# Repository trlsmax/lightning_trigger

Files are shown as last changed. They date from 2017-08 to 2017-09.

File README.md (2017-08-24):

# lightning_trigger
trigger the camera to capture lightning

sensor and filter circuit come from this [BLOG][1]

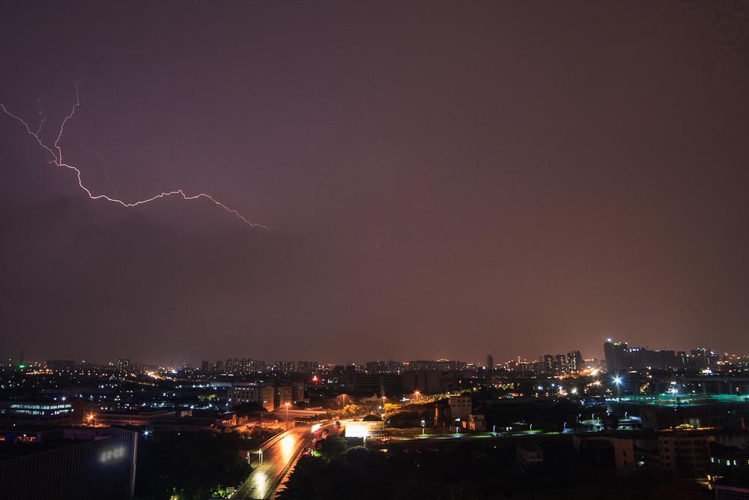
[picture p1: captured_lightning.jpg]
Captured Lightning


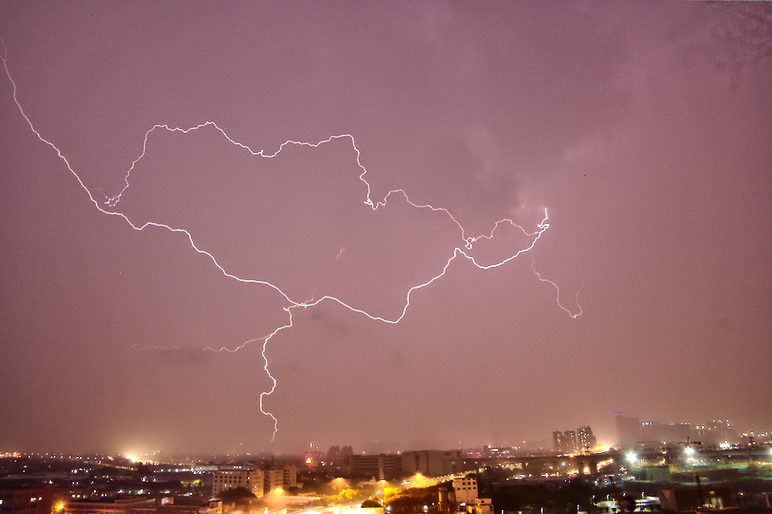
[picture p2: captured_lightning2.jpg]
Captured Lightning 2


[1]:http://diy.viktak.com/2011/03/zeus-lightning-trigger-for-cameras.html

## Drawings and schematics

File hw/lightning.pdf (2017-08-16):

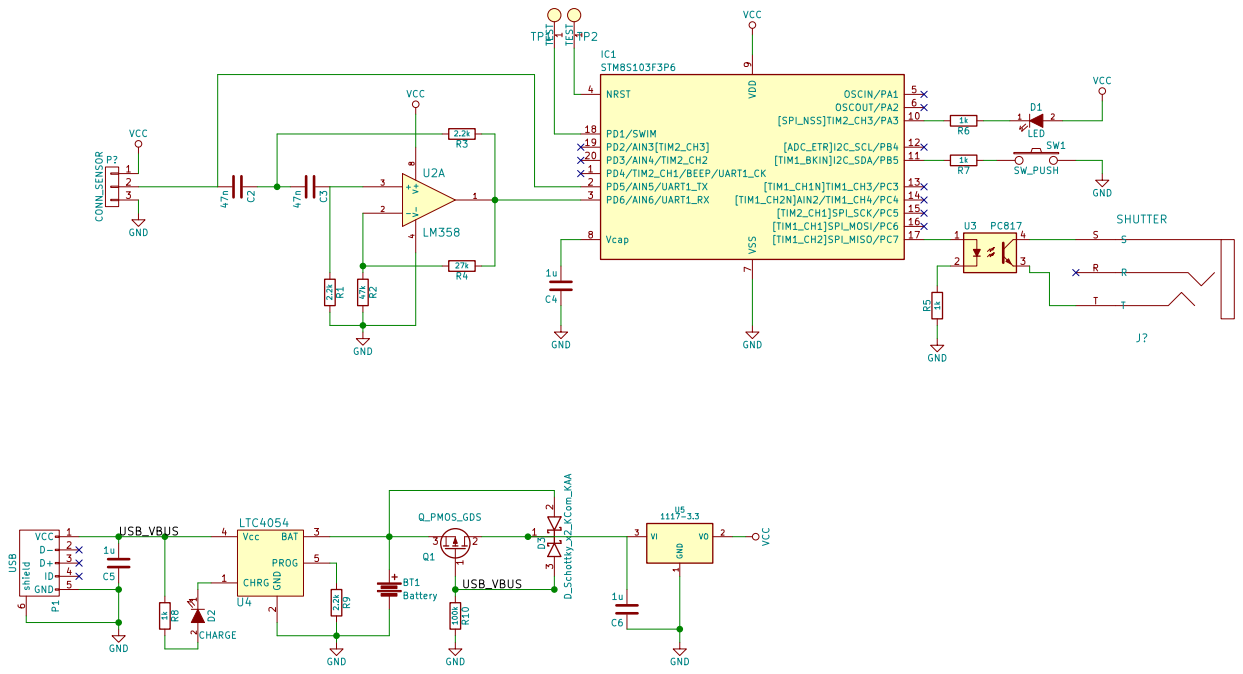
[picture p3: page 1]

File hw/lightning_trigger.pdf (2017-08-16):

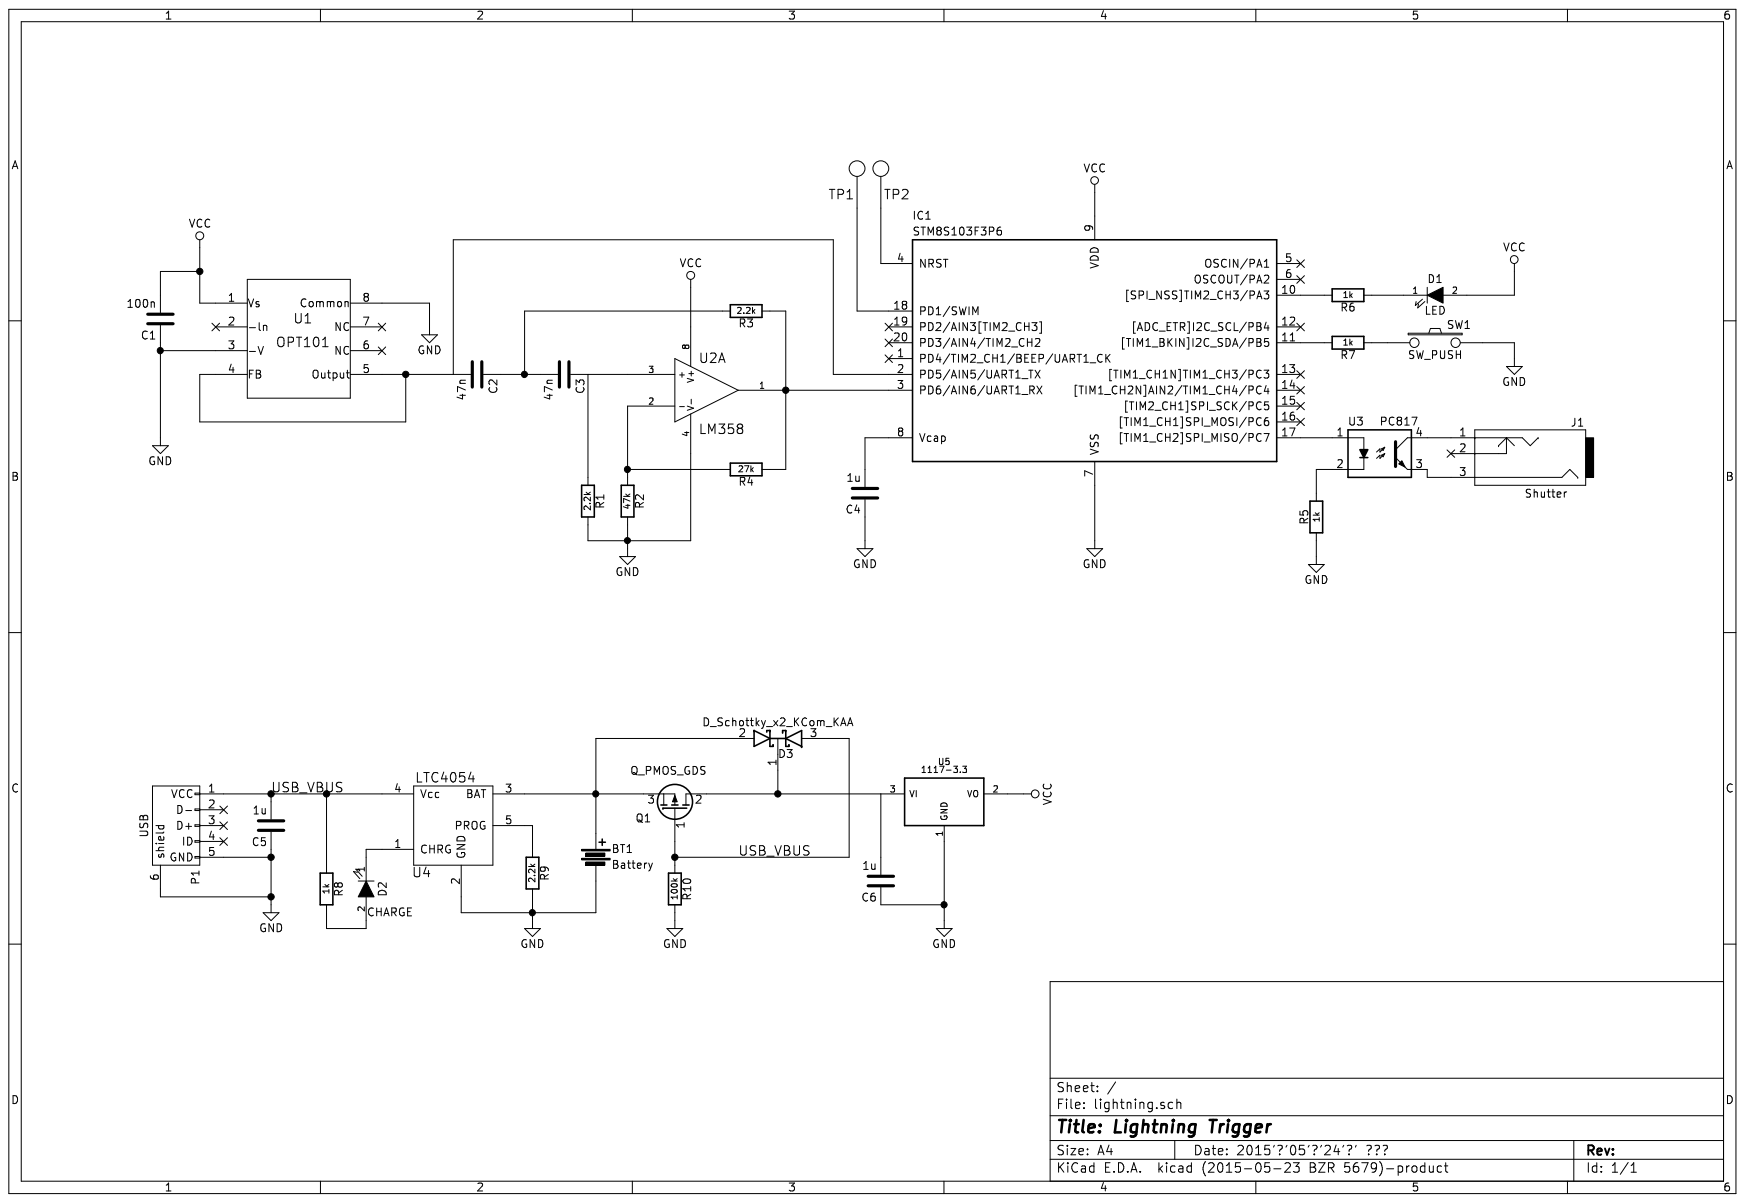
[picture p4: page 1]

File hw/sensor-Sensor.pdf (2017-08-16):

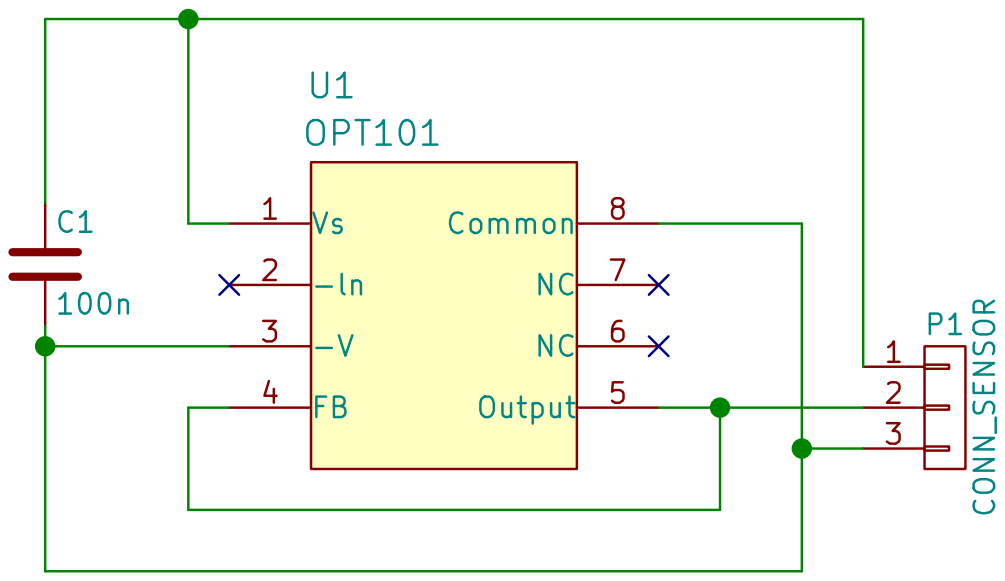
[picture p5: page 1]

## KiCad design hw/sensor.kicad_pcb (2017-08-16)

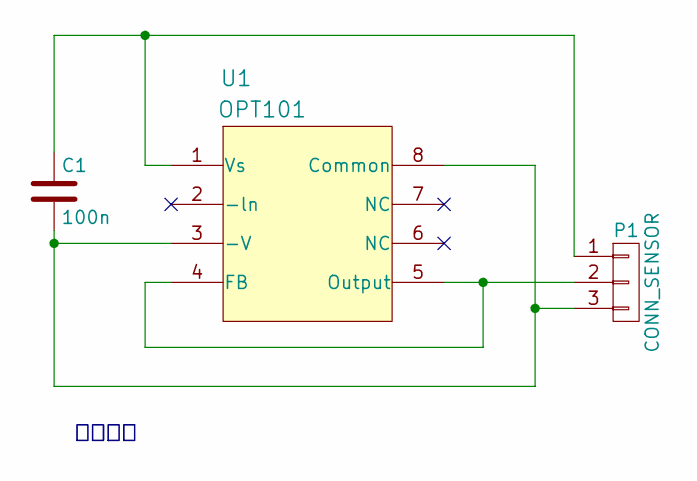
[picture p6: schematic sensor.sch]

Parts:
C1: 100n; C_0603
P1: CONN_SENSOR; Pin_Header_Straight_1x03
U1: OPT101; DIP-8__300_ELL

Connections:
unnamed: C1.1, P1.1, U1.1 (Vs)
unnamed: C1.2, P1.3, U1.3 (-V), U1.8 (Common)
unnamed: P1.2, U1.4 (FB), U1.5 (Output)

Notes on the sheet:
转危为安

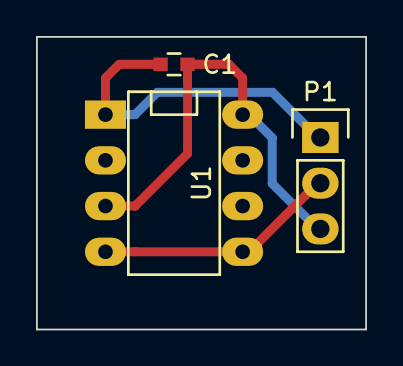
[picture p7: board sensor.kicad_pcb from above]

Board: 2 copper layers, 18.3 x 16.3 mm, 3 parts (0 on the bottom side), 3 nets.

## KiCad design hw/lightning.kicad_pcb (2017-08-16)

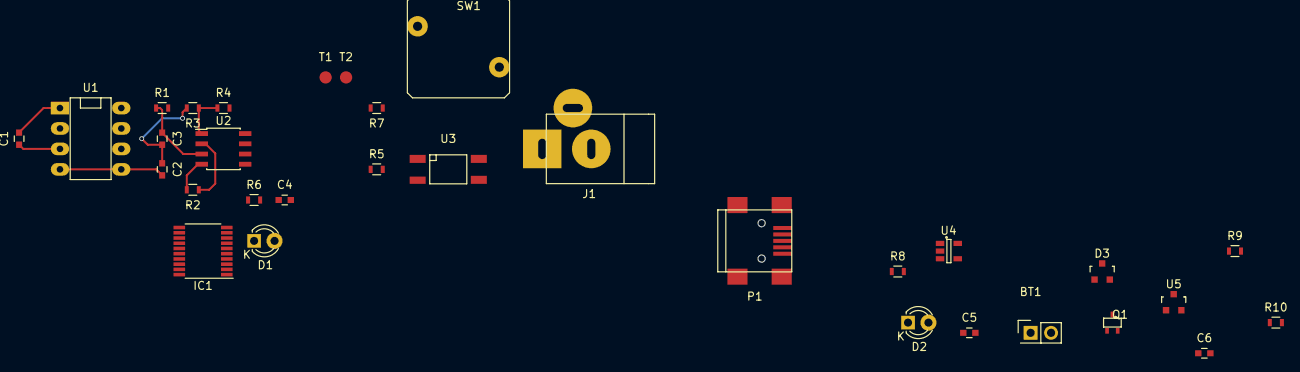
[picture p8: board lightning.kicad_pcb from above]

Board: 2 copper layers, 32 parts (0 on the bottom side), 25 nets.

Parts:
BT1: Battery; Pin_Header_Straight_2x01
C1: 100n; C_0603
C2, C3: 47n; C_0603
C4, C5, C6: 1u; C_0603
D1: LED; LED-3MM
D2: CHARGE; LED-3MM
D3: D_Schottky_x2_KCom_KAA; SOT-23
IC1: STM8S103F3P6; TSSOP-20_4.4x6.5mm_Pitch0.65mm
J1: Shutter; JACK_ALIM
P1: USB_OTG; USB_Mini-B
Q1: Q_PMOS_GDS; sc70
R1, R3, R9: 2.2k; R_0603
R2: 47k; R_0603
R4: 27k; R_0603
R5, R6, R7, R8: 1k; R_0603
R10: 100k; R_0603
SW1: SW_PUSH
T1: SWIM; Measurement_Point_Round-SMD-Pad_Small
T2: NRST; Measurement_Point_Round-SMD-Pad_Small
U1: OPT101; DIP-8__300_ELL
U2: LM358; SOIC-8_3.9x4.9mm_Pitch1.27mm
U3: PC817; Optocoupler_SMD_HandSoldering_KPC357_LTV35x_PC357_SingleCha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
U4: LTC4054; SOT-23-5
U5: NCP1117ST33T3G; SOT-23

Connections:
/USB_VBUS: C5.2, D3.3, P1.1, Q1.1, R8.1, R10.1, U4.4
GND: BT1.2, C4.1, C5.1, C6.1, IC1.7, P1.5, P1.6, R1.2, R2.2, R5.1, R9.2, R10.2, SW1.2, U1.8, U2.4, U4.2, U5.1
unnamed: BT1.1, D3.2, Q1.3, U4.3
unnamed: C1.1, U1.3
unnamed: C2.1, C3.2, R3.2
unnamed: C2.2, IC1.2, U1.4, U1.5
unnamed: C3.1, R1.1, U2.3
unnamed: C4.2, IC1.8
unnamed: C6.2, D3.1, Q1.2, U5.3
unnamed: D1.1, R6.1
unnamed: D2.1, U4.1
unnamed: D2.2, R8.2
unnamed: IC1.3, R3.1, R4.1, U2.1
unnamed: IC1.4, T2.1
unnamed: IC1.10, R6.2
unnamed: IC1.11, R7.2
unnamed: IC1.17, U3.1
unnamed: IC1.18, T1.1
unnamed: J1.1, U3.4
unnamed: J1.3, U3.3
unnamed: R2.1, R4.2, U2.2
unnamed: R5.2, U3.2
unnamed: R7.1, SW1.1
unnamed: R9.1, U4.5
VCC: C1.2, D1.2, IC1.9, U1.1, U2.8, U5.2

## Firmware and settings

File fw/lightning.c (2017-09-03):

#include <stdio.h>
#include <string.h>
#include "stm8s.h"

#define FALSE 0
#define TRUE 1

//#define DEBUG_ENABLE

/* mirror lockup will stop when there is no 
 * shutter trigger in 25 seconds on Canon 350D
 * */
#define MIRROR_LOCKUP_AUTO_RESTART

#define BG_INTERVAL 5000           // get background light level every BG_INTERVAL sec
#define TRIGGER_OFFSET 5

#ifdef MIRROR_LOCKUP_AUTO_RESTART
#define MIRROR_TIMEOUT 30500
#endif

#ifdef STM8S105                 // config for STM8S-DISCOVERY board
#define CH_BACKGROUND 4
#define CH_HIGHPASS 9
#define SHUTTER_PORT GPIOB
#define SHUTTER_PIN 0x80        //PB7
#define UART UART2
#define UART_SR_TXE UART2_SR_TXE
#define UART_CR2_TEN UART2_CR2_TEN
#define TXD_PORT GPIOD
#define TXD_PIN 0x20            //PD5
#define ML_PORT GPIOD
#define ML_PIN 0x80
#elif defined(STM8S103)         // config for my STM8S103 board
#define CH_BACKGROUND 5
#define CH_HIGHPASS 6
#define SHUTTER_PORT GPIOC
#define SHUTTER_PIN 0x80        //PB7
#define UART UART1
#define UART_SR_TXE UART1_SR_TXE
#define UART_CR2_TEN UART1_CR2_TEN
#define TXD_PORT GPIOD
#define TXD_PIN 0x20            //PD5
#define ML_PORT GPIOB
#define ML_PIN 0x20
#endif

volatile bool lightning_trg = FALSE;
bool mirror_lockup_enable = FALSE;
uint16_t *buf_ptr;
volatile uint16_t time_cnt = 0;

#ifdef MIRROR_LOCKUP_AUTO_RESTART
volatile bool do_mirror_lockup = FALSE;
volatile uint16_t mirror_cnt = 0;
#endif

void delay_ms(uint16_t t)
{
    time_cnt = t;
    while(time_cnt > 0);
}

#ifdef DEBUG_ENABLE
bool bg_flag = FALSE;
uint16_t tmp;
/* ========================================================================== */
/**
 * @brief   putchar send a char to UART2 for printf func
 *
 * @param   c char to send
 *
 * @return  
 */
/* ========================================================================== */
int putchar(int c)
{
    while(!(UART->SR & UART_SR_TXE));
    UART->DR = (uint8_t)c;
    return 0;
}
#endif

/* ========================================================================== */
/**
 * @brief   main main func
 */
/* ========================================================================== */
void main(void) 
{
    uint32_t i = 0;

    CLK->CKDIVR = 0x00;                             // Set the frequency to 16 MHz
    CLK->PCKENR1 = 0x88;                            // Enable TIM1 & UART2 peripherals
    CLK->PCKENR2 = 0x08;                            // Enable ADC1 peripherals

    /* setting up shutter io */
    SHUTTER_PORT->DDR |= SHUTTER_PIN;
    SHUTTER_PORT->CR1 |= SHUTTER_PIN;
    SHUTTER_PORT->CR2 |= SHUTTER_PIN;
    SHUTTER_PORT->ODR = 0;

    /* mirror lockup pin setup */
    ML_PORT->CR1 |= ML_PIN;                         //input , pull up, no interrupt

#ifdef DEBUG_ENABLE
    TXD_PORT->DDR |= TXD_PIN;                       // Put TX line on
    TXD_PORT->CR1 |= TXD_PIN;
    TXD_PORT->CR2 |= TXD_PIN;

    UART->CR2 = UART_CR2_TEN;                       // Allow TX & RX
    UART->BRR2 = 0x0B; UART->BRR1 = 0x08;           // 115200 baud
#endif

    buf_ptr = (uint16_t *)&ADC1->DB0RH;             //set a pointer to ADC data buffer
    /* set adc1 to continue buffered mode to get background light level 
     * and set it to high threathold for lightning trigger*/
    ADC1->CR1 &= ~ADC1_CR1_ADON;                    //power off
    ADC1->CR2 |= ADC1_CR2_ALIGN;                    //right alignment
    ADC1->CR1 |= ADC1_CR1_CONT;                     //Continuous
    ADC1->CR3 |= ADC1_CR3_DBUF;                     //buffer
    ADC1->CSR |= (ADC1_CSR_CH & CH_BACKGROUND);     // set input channel
    ADC1->CSR |= ADC1_CSR_EOCIE;                    //set end of conversion interrupt
    ADC1->TDRL = 0xFF;                              //disable sthmit trigger
    ADC1->TDRH = 0xFF;
    ADC1->HTRL = ADC1_HTRL_RESET_VALUE;
    ADC1->HTRH = ADC1_HTRH_RESET_VALUE;
    ADC1->LTRL = ADC1_LTRL_RESET_VALUE;
    ADC1->LTRH = ADC1_LTRH_RESET_VALUE;
    ADC1->CR1 |= ADC1_CR1_ADON;                     //power on
    ADC1->CR1 |= ADC1_CR1_ADON;                     //start conversion

    /*
     * set up 1ms timer interrupt
     * to get background light level every BG_INTERVAL ms
     */
    TIM1->ARRH = (uint8_t)(500 >> 8);               //auto reload value
    TIM1->ARRL = (uint8_t)500;
    TIM1->PSCRH = 0;                                //prescaler
    TIM1->PSCRL = (uint8_t)31;
    TIM1->IER |= TIM1_IER_UIE;                      //enable update interrupt
    TIM1->RCR = 0;                                  //disable repeat counter
    TIM1->CR1 = TIM1_CR1_RESET_VALUE;
    TIM1->CR1 |= TIM1_CR1_ARPE;                     //auto reload
    TIM1->CR1 |= TIM1_CR1_CEN;

    enableInterrupts();
    delay_ms(1000);

    // read mirror lockup switch
    mirror_lockup_enable = ((ML_PORT->IDR & ML_PIN) == 0);

    if (mirror_lockup_enable) {
        //mirror lockup enable
        SHUTTER_PORT->ODR |= SHUTTER_PIN;
        delay_ms(100);
        SHUTTER_PORT->ODR &= ~SHUTTER_PIN;
    }

    do {
        /* trigger camera */
        if (lightning_trg) {
            SHUTTER_PORT->ODR |= SHUTTER_PIN;
#ifdef DEBUG_ENABLE
            //print trigger light level
            printf("lightning = %d !\n\r", tmp);
#endif
            delay_ms(100);
            SHUTTER_PORT->ODR &= ~SHUTTER_PIN;

            if (mirror_lockup_enable) {
                // here, shutter duration should less than 2000 ms
                delay_ms(2000);
                //mirror lockup enable
                SHUTTER_PORT->ODR |= SHUTTER_PIN;
                delay_ms(100);
                SHUTTER_PORT->ODR &= ~SHUTTER_PIN;
#ifdef MIRROR_LOCKUP_AUTO_RESTART
                //reset mirror timeout counter
                mirror_cnt = MIRROR_TIMEOUT;
#endif
            }

            lightning_trg = FALSE;
            ADC1->CR1 |= ADC1_CR1_ADON;                         //power on
            ADC1->CR1 |= ADC1_CR1_ADON;                         //start conversion
        }


#ifdef DEBUG_ENABLE
        //print background light level
        if (bg_flag) {
            bg_flag = FALSE;
            printf("background = %d\n\r", tmp);
        }
#endif

#ifdef MIRROR_LOCKUP_AUTO_RESTART
        if (mirror_lockup_enable && do_mirror_lockup) {
            do_mirror_lockup = FALSE;
            //mirror lockup enable
            SHUTTER_PORT->ODR |= SHUTTER_PIN;
            delay_ms(100);
            SHUTTER_PORT->ODR &= ~SHUTTER_PIN;
            //reset mirror timeout counter
            mirror_cnt = MIRROR_TIMEOUT;
        }
#endif
    } while(1);
}

/* ========================================================================== */
/**
 * @brief   tim1_update tim1 ISR , 1 sec timer, count BG_INTERVAL sec to
 *                      get background light level
 *
 * @param   none
 */
/* ========================================================================== */
void tim1_update(void) __interrupt(ISR_TIM1_OVF)
{
    static uint16_t sec = 0;

    if (time_cnt > 0)
        time_cnt--;

#ifdef MIRROR_LOCKUP_AUTO_RESTART
    if (mirror_cnt > 0) {
        if (--mirror_cnt == 0)
            do_mirror_lockup = TRUE;
    }
#endif

    if (sec++ > BG_INTERVAL) {
        sec = 0;
        /*************************************************
         * set adc1 to buffered continue mode
         * and get background light level
         * **********************************************/
        ADC1->CR1 &= ~ADC1_CR1_ADON;                    //power off
        ADC1->CR3 |= ADC1_CR3_DBUF;                     //buffer mode
        //ADC1->CSR &= ~ADC1_CSR_CH;
        //ADC1->CSR |= (ADC1_CSR_CH & CH_BACKGROUND);   //select background channel
        //ADC1->CSR |= ADC1_CSR_EOCIE;                  //enable end of conversion isr
        //ADC1->CSR &= ~ADC1_CSR_AWDIE;                 //disable AWD
        ADC1->CSR = 0x24;
        ADC1->CR1 |= ADC1_CR1_ADON;                     //power on
        ADC1->CR1 |= ADC1_CR1_ADON;                     //start conversion
    }

    TIM1->SR1 &= ~(TIM1_SR1_UIF);                       //clear update flag
}

/* ========================================================================== */
/**
 * @brief   adc ADC1 ISR, background light level calculate and setting
 *              lightning trigger level, when lightning detected, trigger
 *              the camera shutter
 *
 * @param   none
 */
/* ========================================================================== */
void adc(void) __interrupt(ISR_ADC1)
{
    uint8_t i;
    uint32_t sum;

    if (ADC1->CSR & ADC1_CSR_AWD) {                     //AWD interrupt
        ADC1->CSR &= ~ADC1_CSR_AWDIE;                   //disable AWD interrupt
        /*************************************************
         * detected lightning bolt
         * and trigger camera shutter
         * **********************************************/
        if (lightning_trg == FALSE) {
            SHUTTER_PORT->ODR |= SHUTTER_PIN;           //trigger camera shutter
            ADC1->CR1 &= ~ADC1_CR1_ADON;                    //power off
            lightning_trg = TRUE;
#ifdef DEBUG_ENABLE
            tmp = *(uint16_t*)&ADC1->DRH;               //store the trigger value for print
#endif
        }
        ADC1->CSR &= ~ADC1_CSR_AWD;                     //clear interrupt flag
        ADC1->CSR &= ~ADC1_CSR_EOC;                     //clear interrupt flag
        ADC1->CSR |= ADC1_CSR_AWDIE;                    //enable AWD interrupt
    } else if (ADC1->CSR & ADC1_CSR_EOC) {              //end of conversion
        ADC1->CR1 &= ~ADC1_CR1_ADON;                    //power off

        /***************************************************
         * everage 8 sample to be the background light level
         **************************************************/
        sum = 0;
        for(i = 0; i < 10; i++)
            if (sum < buf_ptr[i])
                sum = buf_ptr[i];
        sum += TRIGGER_OFFSET;

#ifdef DEBUG_ENABLE
        tmp = sum;                                      //store everage value for print
        bg_flag = TRUE;                                 //print flag
#endif
        /*************************************************
         * set adc1 to non-buffered continue mode
         * and trigger by light level greater that 
         * high threathold
         * **********************************************/
        ADC1->CR3 &= ~ADC1_CR3_DBUF;                        //buffer mode
        //ADC1->CSR &= ~ADC1_CSR_EOC;                       //clear interrupt flag
        //ADC1->CSR &= ~ADC1_CSR_CH;
        //ADC1->CSR |= (ADC1_CSR_CH & CH_HIGHPASS);         //select highpass channel
        //ADC1->CSR &= ~ADC1_CSR_EOCIE;                     //set end of conversion interrupt
        //ADC1->CSR |= ADC1_CSR_AWDIE;                      //enable AWD interrupt
        ADC1->CSR = 0x19;
        ADC1->HTRL = (sum & 3);                             //set AWD
        ADC1->HTRH = (sum >> 2);
        ADC1->CR1 |= ADC1_CR1_ADON;                         //power on
        ADC1->CR1 |= ADC1_CR1_ADON;                         //start conversion
    }
}

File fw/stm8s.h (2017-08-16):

/**
  ******************************************************************************
  * @file    stm8s.h
  * @author  MCD Application Team
  * @version V2.1.0
  * @date    18-November-2011
  * @brief   This file contains all HW registers definitions and memory mapping.
  ******************************************************************************
  * @attention
  *
  * THE PRESENT FIRMWARE WHICH IS FOR GUIDANCE ONLY AIMS AT PROVIDING CUSTOMERS
  * WITH CODING INFORMATION REGARDING THEIR PRODUCTS IN ORDER FOR THEM TO SAVE
  * TIME. AS A RESULT, STMICROELECTRONICS SHALL NOT BE HELD LIABLE FOR ANY
  * DIRECT, INDIRECT OR CONSEQUENTIAL DAMAGES WITH RESPECT TO ANY CLAIMS ARISING
  * FROM THE CONTENT OF SUCH FIRMWARE AND/OR THE USE MADE BY CUSTOMERS OF THE
  * CODING INFORMATION CONTAINED HEREIN IN CONNECTION WITH THEIR PRODUCTS.
  *
  * <h2><center>&copy; COPYRIGHT 2011 STMicroelectronics</center></h2>
  ******************************************************************************
  */

/* Define to prevent recursive inclusion -------------------------------------*/
#ifndef __STM8S_H
#define __STM8S_H

/** @addtogroup STM8S_StdPeriph_Driver
  * @{
  */

/* Uncomment the line below according to the target STM8S or STM8A device used in your
   application. */

 /* #define STM8S208 */      /*!< STM8S High density devices with CAN */
 /* #define STM8S207 */      /*!< STM8S High density devices without CAN */
 /* #define STM8S007 */      /*!< STM8S Value Line High density devices */
 /* #define STM8AF52Ax */    /*!< STM8A High density devices with CAN */
 /* #define STM8AF62Ax */    /*!< STM8A High density devices without CAN */
 /* #define STM8S105 */     /*!< STM8S Medium density devices */
 /* #define STM8S005 */      /*!< STM8S Value Line Medium density devices */
 /* #define STM8AF626x */    /*!< STM8A Medium density devices */
 /* #define STM8S103 */      /*!< STM8S Low density devices */
 /* #define STM8S003 */      /*!< STM8S Value Line Low density devices */
 /* #define STM8S903 */      /*!< STM8S Low density devices */

/*   Tip: To avoid modifying this file each time you need to switch between these
        devices, you can define the device in your toolchain compiler preprocessor.

  - High-Density STM8A devices are the STM8AF52xx STM8AF6269/8x/Ax,
    STM8AF51xx, and STM8AF6169/7x/8x/9x/Ax microcontrollers where the Flash memory
    density ranges between 32 to 128 Kbytes
  - Medium-Density STM8A devices are the STM8AF622x/4x, STM8AF6266/68,
    STM8AF612x/4x, and STM8AF6166/68 microcontrollers where the Flash memory
    density ranges between 8 to 32 Kbytes
  - High-Density STM8S devices are the STM8S207xx, STM8S007 and STM8S208xx microcontrollers
    where the Flash memory density ranges between 32 to 128 Kbytes.
  - Medium-Density STM8S devices are the STM8S105x and STM8S005 microcontrollers
    where the Flash memory density ranges between 16 to 32-Kbytes.
  - Low-Density STM8S devices are the STM8S103xx, STM8S003 and STM8S903xx microcontrollers
    where the Flash density is 8 Kbytes. */

#if !defined (STM8S208) && !defined (STM8S207) && !defined (STM8S105) && \
    !defined (STM8S103) && !defined (STM8S903) && !defined (STM8AF52Ax) && \
    !defined (STM8AF62Ax) && !defined (STM8AF626x) && !defined (STM8S007) && \
    !defined (STM8S003)&& !defined (STM8S005)
 #error "Please select first the target STM8S/A device used in your application (in stm8s.h file)"
#endif

/******************************************************************************/
/*                   Library configuration section                            */
/******************************************************************************/
/* Check the used compiler */
#if defined(__CSMC__)
 #define _COSMIC_
#elif defined(__RCST7__)
 #define _RAISONANCE_
#elif defined(__ICCSTM8__)
 #define _IAR_
#elif defined(__SDCC)
 #define _SDCC_
#else
 #error "Unsupported Compiler!"          /* Compiler defines not found */
#endif

#if !defined  USE_STDPERIPH_DRIVER
/* Comment the line below if you will not use the peripherals drivers.
   In this case, these drivers will not be included and the application code will be
   based on direct access to peripherals registers */
 //#define USE_STDPERIPH_DRIVER
#endif

/**
  * @brief  In the following line adjust the value of External High Speed oscillator (HSE)
   used in your application

   Tip: To avoid modifying this file each time you need to use different HSE, you
        can define the HSE value in your toolchain compiler preprocessor.
  */
#if !defined  HSE_Value
 #if defined (STM8S208) || defined (STM8S207) || defined (STM8S007) || defined (STM8AF52Ax) || \
     defined (STM8AF62Ax)
  #define HSE_VALUE ((u32)24000000) /* Value of the External oscillator in Hz*/
 #else
  #define HSE_VALUE ((u32)14745600) /* Value of the External oscillator in Hz*/
 #endif /* STM8S208 || STM8S207 || STM8S007 || STM8AF62Ax || STM8AF52Ax */
#endif /* HSE_Value */

/**
  * @brief  Definition of Device on-chip RC oscillator frequencies
  */
#define HSI_VALUE   ((uint32_t)16000000) /*!< Typical Value of the HSI in Hz */
#define LSI_VALUE   ((uint32_t)128000)   /*!< Typical Value of the LSI in Hz */

#ifdef _COSMIC_
 #define FAR  @far
 #define NEAR @near
 #define TINY @tiny
 #define EEPROM @eeprom
 #define CONST  const
#elif defined (_RAISONANCE_) /* __RCST7__ */
 #define FAR  far
 #define NEAR data
 #define TINY page0
 #define EEPROM eeprom
 #define CONST  code
 #if defined (STM8S208) || defined (STM8S207) || defined (STM8S007) || defined (STM8AF52Ax) || \
     defined (STM8AF62Ax)
   /*!< Used with memory Models for code higher than 64K */
  #define MEMCPY fmemcpy
 #else /* STM8S903, STM8S103, STM8S003, STM8S105, STM8AF626x */
  /*!< Used with memory Models for code less than 64K */
  #define MEMCPY memcpy
 #endif /* STM8S208 or STM8S207 or STM8S007 or STM8AF62Ax or STM8AF52Ax */
#else /*_IAR_*/
 #define FAR  __far
// #define NEAR __near
 #define NEAR //hack SDCC gets confused by __near
 #define TINY __tiny
 #define EEPROM __eeprom
 #define CONST  const
#endif /* __CSMC__ */

/* For FLASH routines, select whether pointer will be declared as near (2 bytes,
   to handle code smaller than 64KB) or far (3 bytes, to handle code larger
   than 64K) */

#if defined (STM8S105) || defined (STM8S005) || defined (STM8S103) || defined (STM8S003) || \
    defined (STM8S903) || defined (STM8AF626x)
/*!< Used with memory Models for code smaller than 64K */
 //#define PointerAttr NEAR
 #define PointerAttr NEAR

#else /* STM8S208 or STM8S207 or STM8AF62Ax or STM8AF52Ax */
/*!< Used with memory Models for code higher than 64K */
 #define PointerAttr FAR
#endif /* STM8S105 or STM8S103 or STM8S003 or STM8S903 or STM8AF626x */

/* Uncomment the line below to enable the FLASH functions execution from RAM */
#if !defined (RAM_EXECUTION)
/* #define RAM_EXECUTION  (1) */
#endif /* RAM_EXECUTION */
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

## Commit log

2017-08-16 add fw and hw
    [lightning.kicad_pcb, lightning.sch, power.sch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]
2017-09-03 longer mirror lockup timerout

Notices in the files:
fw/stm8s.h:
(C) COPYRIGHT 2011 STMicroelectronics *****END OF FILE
